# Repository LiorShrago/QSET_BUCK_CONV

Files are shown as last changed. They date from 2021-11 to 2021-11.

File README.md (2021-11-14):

# QSET_BUCK_CONV
Buck Converter which can have an input votlage of 12V-9V and then step-down the voltage to 5V. There is also an E-Fuse on the output of the Buck converter for extra safety.

Inside the folder there are 3 more folder.
1 - One folder that all the EAGLE library files needed to see the schematic

2 - One folder holds the EAGLE schematic and PCB files

3 - One folder has the TinaTi, spice files used to test the buck converter before manufcaturing the PCB. TinaTi is a spice software that TI offers for their components,
it helped check that the Buck converter transient response and how bad its Output Voltage ripple would be under various loads.

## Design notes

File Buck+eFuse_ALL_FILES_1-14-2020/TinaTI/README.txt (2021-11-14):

## WEBENCH Design 1
Created at Wed Nov 06 23:23:27 PST 2019
**********************************************************
*******************  SIMULATION Instructions  ************
**********************************************************

This TINA Schematic can be opened in TINA-TI and simulated using TINA-TI. 

TINA-TI provides all the conventional DC, transient and frequency domain 
analysis of SPICE and much more. TINA has extensive post-processing capability 
that allows you to format results the way you want them. Virtual instruments 
allow you to select input waveforms and probe circuit nodes voltages and waveforms. 
TINA's schematic capture is truly intuitive - a real "quickstart."

TINA-TI installation requires approximately 500MB. Installation is straight-forward
 and it can be uninstalled easily, if you wish. We bet that you won't.

TINA is a product of DesignSoft exclusively for Texas Instruments. 
This complimentary version is fully functional but does not support some other 
features available with the full version of TINA.

For a complete list of available TINA-TI models, see: SpiceRack -- A Complete List

https://webench.ti.com/webench5/spicemodels/?DCMP=hpa_hpa_elabs&HQS=spicerack#search=tina

Download TINA-TI:
http://www.ti.com/tool/TINA-TI

Installation guide:
https://training.ti.com/tina-ti-video-training-series

More about WEBENCH simulation export to TINA-TI:
http://www.ti.com/design-tools/webench-power-design/tina-export.html

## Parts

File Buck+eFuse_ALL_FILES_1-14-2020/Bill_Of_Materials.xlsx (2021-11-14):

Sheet: Sheet2
Components | Count | Unit Price | Cost | Link
CGA4F2C0G1H153J085AA | 1 | $0.47 | $0.47 | https://www.digikey.ca/product-detail/en/tdk-corporation/CGA4F2C0G1H153J085AA/445-6948-1-ND/2672966
CRCW04029K53FKED | 1 | $0.15 | $0.15 | https://www.digikey.ca/product-detail/en/vishay-dale/CRCW04029K53FKED/541-9.53KLCT-ND/1183235
C3225X7R1H106M250AC | 3 | $1.54 | $4.62 | https://www.digikey.ca/product-detail/en/tdk-corporation/C3225X7R1H106M250AC/445-14933-1-ND/3956599
TPS54A24RTWR | 1 | $7.27 | $7.27 | https://www.digikey.ca/product-detail/en/texas-instruments/TPS54A24RTWR/296-53562-1-ND/10273292
GRM32ER61C476KE15L | 2 | $1.06 | $2.12 | https://www.digikey.ca/product-detail/en/murata-electronics/GRM32ER61C476KE15L/490-6539-1-ND/3845736
C1608X7R1V105K080AC | 1 | $0.28 | $0.28 | https://www.digikey.ca/product-detail/en/tdk-corporation/C1608X7R1V105K080AC/445-7414-1-ND/2733486
GRM033R71A822KA01D | 1 | $0.10 | $0.10 | https://www.digikey.ca/product-detail/en/murata-electronics/GRM033R71A822KA01D/490-11356-1-ND/5333196
CL21C150JBANNNC | 1 | $0.14 | $0.14 | https://www.digikey.ca/product-detail/en/samsung-electro-mechanics/CL21C150JBANNNC/1276-1163-1-ND/3889249
GRM188R72A104KA35D | 1 | $0.40 | $0.11 | https://www.digikey.ca/product-detail/en/murata-electronics/GRM188R72A104KA35D/490-3285-1-ND/702826
GRM155R71C104KA88D | 1 | $0.14 | $0.14 | https://www.digikey.ca/product-detail/en/murata-electronics/GRM155R71C104KA88D/490-3261-1-ND/702802
CRCW0402143KFKED | 1 | $0.15 | $0.15 | https://www.digikey.ca/product-detail/en/vishay-dale/CRCW0402143KFKED/541-143KLCT-ND/1183367
CRCW0402100KFKED | 1 | $0.15 | $0.15 | https://www.digikey.ca/product-detail/en/vishay-dale/CRCW0402100KFKED/541-100KLCT-ND/1183351
GRM32ER61C476KE15L | 2 | $1.51 | $3.02 | https://www.digikey.ca/product-detail/en/murata-electronics/GRM32ER61C476KE15L/490-6539-1-ND/3845736
AC0402FR-0744K2L | 1 | $0.15 | $0.15 | https://www.digikey.ca/product-detail/en/yageo/AC0402FR-0744K2L/YAG5295CT-ND/7063638
CRCW04026K04FKEDC | 1 | $0.15 | $0.15 | https://www.digikey.ca/product-detail/en/vishay-dale/CRCW04026K04FKEDC/541-4067-1-ND/7928750
7443330330 | 1 | $3.41 | $3.41 | https://www.digikey.ca/product-detail/en/w-rth-elektronik/7443330330/732-2154-1-ND/2175668
Molex connector | 3 | $1.05 | $3.15 | https://www.digikey.ca/product-detail/en/molex/0705530001/WM4900-ND/114951
4.99Ohm Resistor | 2 | $0.15 | $0.30 | https://www.digikey.ca/product-detail/en/yageo/RC0805FR-074R99L/311-4.99CRCT-ND/730884
NIS5452 E-Fuse | 2 | $1.80 | $3.60 | https://www.digikey.ca/product-detail/en/on-semiconductor/NIS5452MT1TXG/NIS5452MT1TXGOSCT-ND/9087304
10uF Cap | 1 | $0.27 | $0.27 | https://www.digikey.ca/product-detail/en/kemet/C0805C106K4PACTU/399-8012-1-ND/3471735
1uF Cap | 1 | $0.14 | $0.14 | https://www.digikey.ca/product-detail/en/samsung-electro-mechanics/CL10B105MO8NNWC/1276-6524-6-ND/5961758
0.1uF Cap | 2 | $0.14 | $0.28 | https://www.digikey.ca/product-detail/en/samsung-electro-mechanics/CL05F104ZO5NNNC/1276-1004-1-ND/3889090
47uF Cap | 1 | $1.11 | $1.11 | https://www.digikey.ca/product-detail/en/murata-electronics/GRM32EC81C476KE15L/490-10531-1-ND/5026469
2.2uF | 1 | $0.23 | $0.23 | https://www.digikey.ca/product-detail/en/yageo/CC0603ZRY5V7BB225/311-3416-1-ND/7164437
Screw Terminals | 2 | $0.00 | $0.00
Total Price: |  |  | $31.51

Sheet: Sheet1
Component Name in Eagle |  | Components | Count | Unit Price | Cost | Link
Ccomp2 | 0.015uF | CGA4F2C0G1H153J085AA | 1 | $0.47 | $0.47 | https://www.digikey.ca/product-detail/en/tdk-corporation/CGA4F2C0G1H153J085AA/445-6948-1-ND/2672966
Rcomp | 9.53kOhm | CRCW04029K53FKED | 1 | $0.15 | $0.15 | https://www.digikey.ca/product-detail/en/vishay-dale/CRCW04029K53FKED/541-9.53KLCT-ND/1183235
Cin/Cin1/Cin2 | 10uF | C3225X7R1H106M250AC | 3 | $1.54 | $4.62 | https://www.digikey.ca/product-detail/en/tdk-corporation/C3225X7R1H106M250AC/445-14933-1-ND/3956599
U1 |  | TPS54A24RTWR | 1 | $7.27 | $7.27 | https://www.digikey.ca/product-detail/en/texas-instruments/TPS54A24RTWR/296-53562-1-ND/10273292
Cout1/Cout2 | 47uF | GRM32ER61C476KE15L | 2 | $1.06 | $2.12 | https://www.digikey.ca/product-detail/en/murata-electronics/GRM32ER61C476KE15L/490-6539-1-ND/3845736
Cinx2 | 1uF | C1608X7R1V105K080AC | 1 | $0.28 | $0.28 | https://www.digikey.ca/product-detail/en/tdk-corporation/C1608X7R1V105K080AC/445-7414-1-ND/2733486
Css | 0.0082uF | GRM033R71A822KA01D | 1 | $0.10 | $0.10 | https://www.digikey.ca/product-detail/en/murata-electronics/GRM033R71A822KA01D/490-11356-1-ND/5333196
C_comp1 | 15pF | CL21C150JBANNNC | 1 | $0.14 | $0.14 | https://www.digikey.ca/product-detail/en/samsung-electro-mechanics/CL21C150JBANNNC/1276-1163-1-ND/3889249
Cinx1 | 0.1uF | GRM188R72A104KA35D | 1 | $0.40 | $0.11 | https://www.digikey.ca/product-detail/en/murata-electronics/GRM188R72A104KA35D/490-3285-1-ND/702826
Cboot | 0.1uF | GRM155R71C104KA88D | 1 | $0.14 | $0.14 | https://www.digikey.ca/product-detail/en/murata-electronics/GRM155R71C104KA88D/490-3261-1-ND/702802
Rt | 143kOhm | CRCW0402143KFKED | 1 | $0.15 | $0.15 | https://www.digikey.ca/product-detail/en/vishay-dale/CRCW0402143KFKED/541-143KLCT-ND/1183367
Rpg | 100kOhm | CRCW0402100KFKED | 1 | $0.15 | $0.15 | https://www.digikey.ca/product-detail/en/vishay-dale/CRCW0402100KFKED/541-100KLCT-ND/1183351
Cout3/Cout4 | 47uF | GRM32ER61C476KE15L | 2 | $1.51 | $3.02 | https://www.digikey.ca/product-detail/en/murata-electronics/GRM32ER61C476KE15L/490-6539-1-ND/3845736
Rfbt | 44.2kOhm | AC0402FR-0744K2L | 1 | $0.15 | $0.15 | https://www.digikey.ca/product-detail/en/yageo/AC0402FR-0744K2L/YAG5295CT-ND/7063638
Rfbb | 6.04kOhm | CRCW04026K04FKEDC | 1 | $0.15 | $0.15 | https://www.digikey.ca/product-detail/en/vishay-dale/CRCW04026K04FKEDC/541-4067-1-ND/7928750
L1 | 3.3uH | 7443330330 | 1 | $3.41 | $3.41 | https://www.digikey.ca/product-detail/en/w-rth-elektronik/7443330330/732-2154-1-ND/2175668
 | Molex connector | Molex connector | 3 | $1.05 | $3.15 | https://www.digikey.ca/product-detail/en/molex/0705530001/WM4900-ND/114951
 | 4.99Ohm Resistor | 4.99Ohm Resistor | 2 | $0.15 | $0.30 | https://www.digikey.ca/product-detail/en/yageo/RC0805FR-074R99L/311-4.99CRCT-ND/730884
 | NIS5452 E-Fuse | NIS5452 E-Fuse | 2 | $1.80 | $3.60 | https://www.digikey.ca/product-detail/en/on-semiconductor/NIS5452MT1TXG/NIS5452MT1TXGOSCT-ND/9087304
 | 10uF Cap | 10uF Cap | 1 | $0.27 | $0.27 | https://www.digikey.ca/product-detail/en/kemet/C0805C106K4PACTU/399-8012-1-ND/3471735
 | 1uF Cap | 1uF Cap | 1 | $0.14 | $0.14 | https://www.digikey.ca/product-detail/en/samsung-electro-mechanics/CL10B105MO8NNWC/1276-6524-6-ND/5961758
 | 0.1uF Cap | 0.1uF Cap | 2 | $0.14 | $0.28 | https://www.digikey.ca/product-detail/en/samsung-electro-mechanics/CL05F104ZO5NNNC/1276-1004-1-ND/3889090
 | 47uF Cap | 47uF Cap | 1 | $1.11 | $1.11 | https://www.digikey.ca/product-detail/en/murata-electronics/GRM32EC81C476KE15L/490-10531-1-ND/5026469
 | 2.2uF | 2.2uF | 1 | $0.23 | $0.23 | https://www.digikey.ca/product-detail/en/yageo/CC0603ZRY5V7BB225/311-3416-1-ND/7164437
 | Screw Terminals | Screw Terminals | 2 | $0.00 | $0.00
 |  | Total Price: |  |  | $31.51

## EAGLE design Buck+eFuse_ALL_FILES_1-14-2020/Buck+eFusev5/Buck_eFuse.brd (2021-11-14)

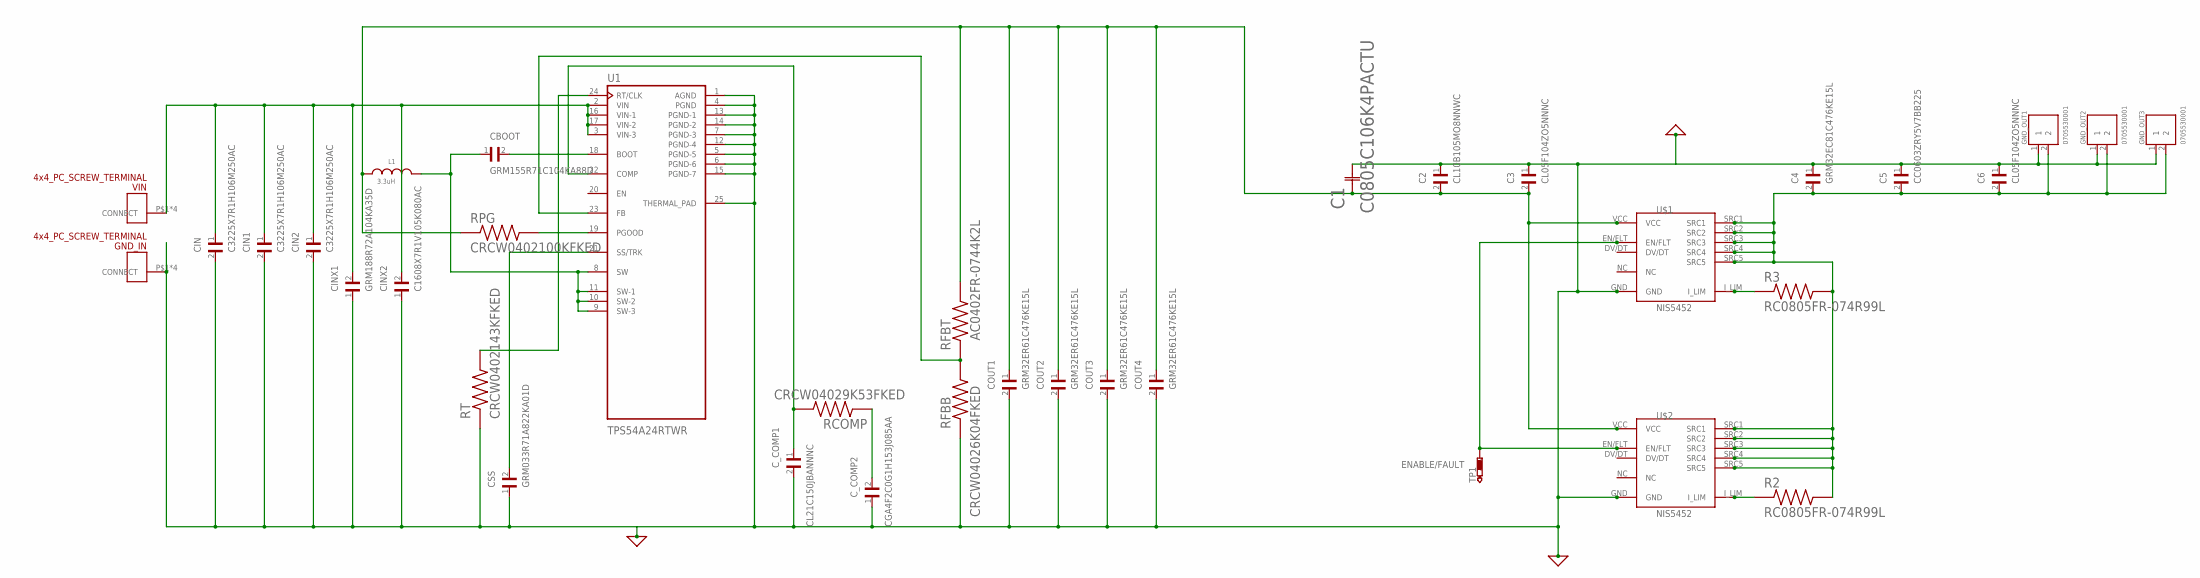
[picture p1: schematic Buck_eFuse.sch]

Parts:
C1: C0805C106K4PACTU; CAP_C0805
C2: CL10B105MO8NNWC; CAPC1608X90N
C3, C6: CL05F104ZO5NNNC; CAPC1005X55N
C4: GRM32EC81C476KE15L; CAPC3225X270N
C5: CC0603ZRY5V7BB225; CAPC1608X90
CBOOT: GRM155R71C104KA88D; CAPC1005X55N
CIN, CIN1, CIN2: C3225X7R1H106M250AC; CAPC3225X280N
CINX1: GRM188R72A104KA35D; CAPC1608X90N
CINX2: C1608X7R1V105K080AC; CAPC1608X90N
COUT1, COUT2, COUT3, COUT4: GRM32ER61C476KE15L; CAPC3225X270N
CSS: GRM033R71A822KA01D; CAPC0603X33N
C_COMP1: CL21C150JBANNNC; CAPC2012X140N
C_COMP2: CGA4F2C0G1H153J085AA; CAPC2012X100N
GND_IN: 2X2_PC_SCREW_TERMINAL; SCREW_TERMINAL
GND_OUT1, GND_OUT2, GND_OUT3: 0705530001; MOLEX_0705530001
L1: 3.3uH; WE-HCC_1090
R2, R3: RC0805FR-074R99L; RESC2012X60N
RCOMP: CRCW04029K53FKED; RESC1005X40N
RFBB: CRCW04026K04FKED; RESC1005X40N
RFBT: AC0402FR-0744K2L; RESC1005X37N
RPG: CRCW0402100KFKED; RESC1005X40N
RT: CRCW0402143KFKED; RESC1005X40N
TP1: PTR1B2,54; B2,54
U1: TPS54A24RTWR; VQFN50P400X400X100-24N
U$1, U$2: NIS5452; WDFN10
VIN: 2X2_PC_SCREW_TERMINAL; SCREW_TERMINAL

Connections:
0: C1.2, C2.1, C3.1, C4.1, C5.1, C6.1, CIN.2, CIN1.2, CIN2.2, CINX1.1, CINX2.1, COUT1.2, COUT2.2, COUT3.2, COUT4.2, CSS.1, C_COMP1.2, C_COMP2.1, GND_IN.P$1, GND_IN.P$2, GND_IN.P$3, GND_IN.P$4, GND_OUT1.1, GND_OUT2.1, GND_OUT3.1, RFBB.1, RT.1, U1.1 (AGND), U1.4 (PGND), U1.5 (PGND-5), U1.6 (PGND-6), U1.7 (PGND-3), U1.12 (PGND-4), U1.13 (PGND-1), U1.14 (PGND-2), U1.15 (PGND-7), U1.25 (THERMAL_PAD), U$1.GND, U$2.GND
ENABLE/FAULT: TP1.TP, U$1.EN/FLT, U$2.EN/FLT
unnamed: CBOOT.2, U1.18 (BOOT)
unnamed: CBOOT.1, L1.2, U1.8 (SW), U1.9 (SW-3), U1.10 (SW-2), U1.11 (SW-1)
unnamed: R3.1, U$1.I_LIM
unnamed: R2.1, U$2.I_LIM
unnamed: CSS.2, U1.21 (SS/TRK)
unnamed: RT.2, U1.24 (RT/CLK)
unnamed: RPG.2, U1.19 (PGOOD)
unnamed: RFBB.2, RFBT.1, U1.23 (FB)
unnamed: C_COMP1.1, RCOMP.1, U1.22 (COMP)
unnamed: C_COMP2.2, RCOMP.2
unnamed: CIN.1, CIN1.1, CIN2.1, CINX1.2, CINX2.2, U1.2 (VIN), U1.3 (VIN-3), U1.16 (VIN-1), U1.17 (VIN-2), VIN.P$1, VIN.P$2, VIN.P$3, VIN.P$4
unnamed: C1.1, C2.2, C3.2, COUT1.1, COUT2.1, COUT3.1, COUT4.1, L1.1, RFBT.2, RPG.1, U$1.VCC, U$2.VCC
V_OUT: C4.2, C5.2, C6.2, GND_OUT1.2, GND_OUT2.2, GND_OUT3.2, R2.2, R3.2, U$1.SRC1, U$1.SRC2, U$1.SRC3, U$1.SRC4, U$1.SRC5, U$2.SRC1, U$2.SRC2, U$2.SRC3, U$2.SRC4, U$2.SRC5

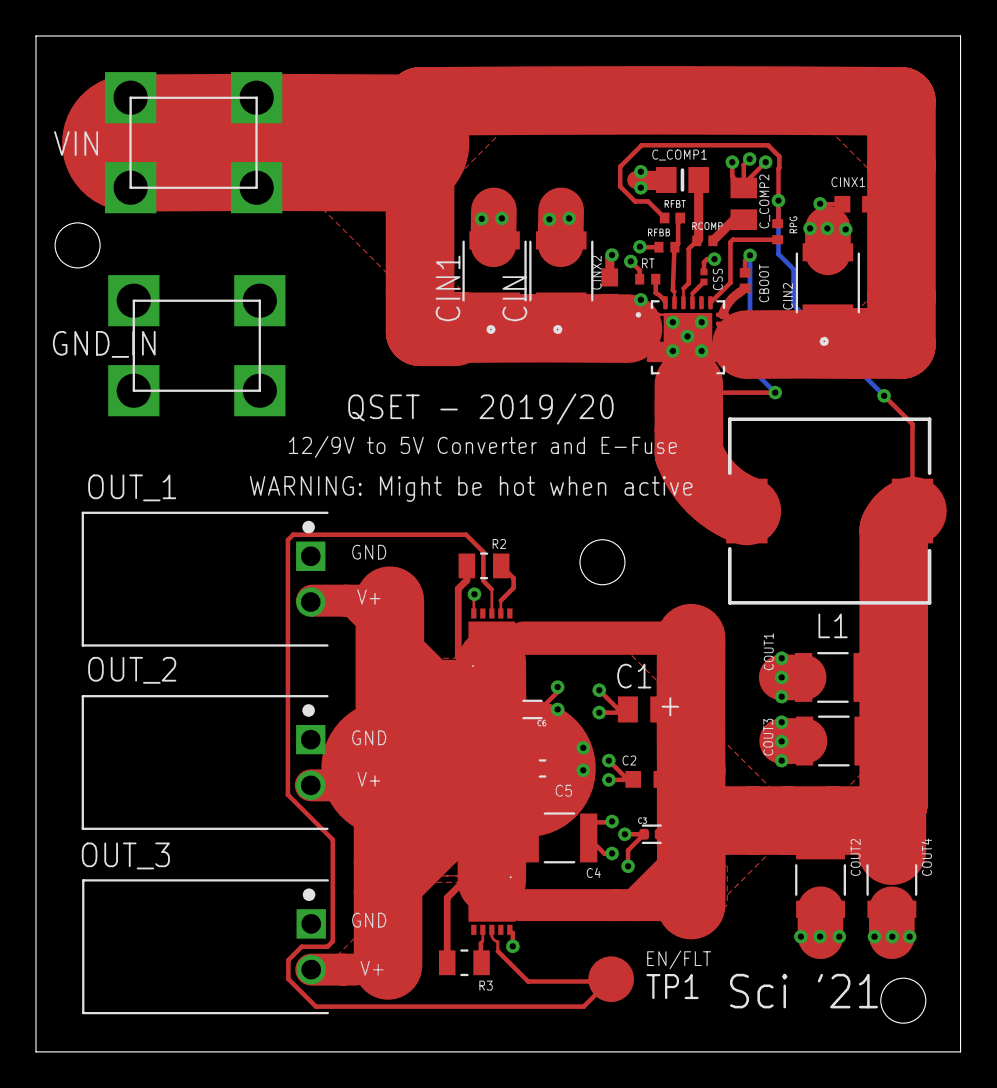
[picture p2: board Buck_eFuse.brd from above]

Board: 2 copper layers, 51.4 x 56.4 mm, 36 parts (0 on the bottom side), 15 nets.

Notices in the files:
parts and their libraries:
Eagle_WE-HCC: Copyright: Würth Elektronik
